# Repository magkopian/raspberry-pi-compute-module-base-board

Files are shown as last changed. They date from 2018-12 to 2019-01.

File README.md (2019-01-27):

Raspberry Pi Compute Module Base Board
================================

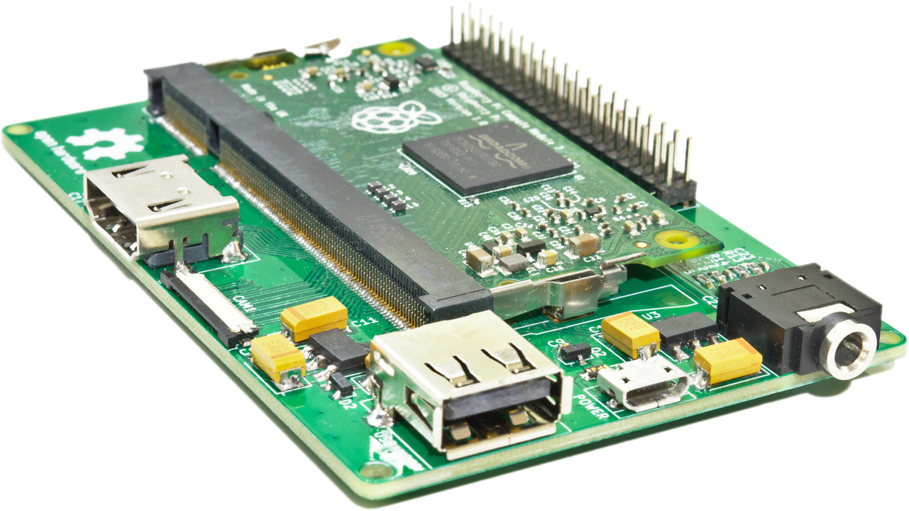
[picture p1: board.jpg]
Device


## Description:

These are the design files for a circuit board intended to be used as a base for other custom PCB designs that make use of the Raspberry Pi Compute Module.

If you want to design a custom PCB based on the Raspberry Pi Compute Module but you have never done it before, this project can serve as a starting point. The board is designed on KiCAD which is an open source and cross-platform EDA software, in order to allow as many people as possible to take advantage of it.

More information about the project can be found on [Instructables](https://www.instructables.com/id/Design-Your-Own-Raspberry-Pi-Compute-Module-PCB/).

## License:

Raspberry Pi Compute Module Base Board

Copyright (C) 2018  Manolis Agkopian

This program is free software: you can redistribute it and/or modify it under the terms of the GNU General Public License as published by the Free Software Foundation, either version 3 of the License, or (at your option) any later version.

This program is distributed in the hope that it will be useful, but WITHOUT ANY WARRANTY; without even the implied warranty of MERCHANTABILITY or FITNESS FOR A PARTICULAR PURPOSE. See the GNU General Public License for more details.

You should have received a copy of the GNU General Public License along with this program. If not, see https://www.gnu.org/licenses/.

### Third party schematic symbols and footprints:

This project makes use of the CM schematic symbols and DDR2 SODIMM fooprint designed by [Joan The Spark](https://github.com/JoanTheSpark/KiCAD) and distrubuted under the [GNU General Public License Version 3](https://www.gnu.org/licenses/gpl.html).

It also makes use of the HDMI connector schematic symbol from the [Digikey KiCAD Library](https://github.com/digikey/digikey-kicad-library) repository which is distrubuted under the [Creative Commons CC-BY-SA 4.0](https://creativecommons.org/licenses/by-sa/4.0).

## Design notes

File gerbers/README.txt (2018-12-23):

Filename                        Description
=============================================================

compute_module-B.Cu.gbl          Bottom Copper Layer

compute_module-In1.Cu.g2         Inner Copper Layer 1

compute_module-In2.Cu.g3		 Inner Copper Layer 2

compute_module-F.Cu.gtl          Front Copper Layer

compute_module-F.Mask.gts        Front Soldermask

compute_module-B.Mask.gbs        Bottom Soldermask

compute_module-F.SilkS.gto       Front Silkscreen

compute_module-B.SilkS.gbo       Bottom Silkscreen

compute_module-Edge.Cuts.gm1     Mechanical Layer (Board Outline)

compute_module.drl               Drill File

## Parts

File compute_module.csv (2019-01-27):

Title | Raspberry Pi Compute Module Base Board
Revision | A
Date
Generated | Sun 27 Jan 2019 08:12:45 AM EET
Company
Comment 1 | Copyright (C) 2018 Manolis Agkopian
Comment 2
Comment 3 | https://www.gnu.org/licenses/gpl.html
Comment 4 | License: GPLv3
Total Parts | 61
Total Unique Parts | 25
Ref | Qty | Value | Footprint | Datasheet
C1 C2 C3 C4 C5 C6 C7 C8 C9 C12 C13 C17 C18 C19 | 14 | 100nF | Capacitors_SMD:C_0402
C10 C11 C14 C15 C16 | 5 | 10uF | Capacitors_Tantalum_SMD:CP_Tantalum_Case-C_EIA-6032-28_Reflow
C20 C21 | 2 | 10uF | Capacitors_SMD:C_0805
C22 C23 | 2 | 33nF | Capacitors_SMD:C_0402
D1 | 1 | GREEN LED | LEDs:LED_0805
D2 D3 | 2 | BAT54 | TO_SOT_Packages_SMD:SOT-23 | https://gr.mouser.com/datasheet/2/427/bat54-58352.pdf
D4 D5 D6 D7 D9 D10 | 6 | BAV99 | TO_SOT_Packages_SMD:SOT-23 | https://gr.mouser.com/datasheet/2/427/bav99g-266615.pdf
D8 | 1 | RED LED | LEDs:LED_0805
F1 | 1 | 2A 6V | Polyfuse_Bourns_MF-PSML:Polyfuse_0805 | https://gr.mouser.com/datasheet/2/54/Bourns_MF-PSML-1159396.pdf
J1 | 1 | 2001-1-2-21-00-BK | HDMI_MOLEX:HDMI_MOLEX_471510001 | https://gr.mouser.com/datasheet/2/276/0471510001_IO_CONNECTORS-170105.pdf
J2 | 1 | JC-128 | jc-128:JC-128 | https://www.tme.eu/en/Document/b2d3db3ed78affad83450dce59a7cdd9/jc-128.pdf
MD1 | 1 | Board_RPi_CM3_200pConnector_multipart | Conn_TE-DDR2-SODIMM:Conn_TE-DDR2-SODIMM-0.6-200P-doublesided | https://www.tme.eu/en/Document/4b83792fd18cac93e642ba1f5319bf1c/1473005-4.pdf
P1 | 1 | POWER | Connectors:USB_Micro-B | https://www.tme.eu/en/Document/b7989e722b05f5084c507fb3ad8f02cb/MX-105017-0001.pdf
P2 | 1 | HOST | Connectors:USB_A | https://gr.mouser.com/datasheet/2/643/bel_SS-52100-001-1216592.pdf
P3 | 1 | CAM1 | ffc_conn:FPC_22 | https://gr.mouser.com/datasheet/2/445/687122183722-1114273.pdf
P4 | 1 | CONN_02X20 | Pin_Headers:Pin_Header_Straight_2x20
Q1 Q3 | 2 | 2N7002P.215 | TO_SOT_Packages_SMD:SOT-23 | https://www.tme.eu/en/Document/fda24b70d66290936384ff869f03745e/2N7002P.pdf
Q2 | 1 | DMP3056L-7 | TO_SOT_Packages_SMD:SOT-23 | https://www.tme.eu/en/Document/250d260377fe1e01ee709e3eafa0c268/DMP3056L.pdf
R1 R6 R7 R8 | 4 | 100K | Resistors_SMD:R_0603_HandSoldering
R2 R3 R11 | 3 | 1K | Resistors_SMD:R_0603_HandSoldering
R4 R5 R9 R10 | 4 | 1.8K | Resistors_SMD:R_0603_HandSoldering
R12 R13 | 2 | 150R | Resistors_SMD:R_0603_HandSoldering
R14 R15 | 2 | 270R | Resistors_SMD:R_0603_HandSoldering
U1 | 1 | REG1117-3.3 | TO_SOT_Packages_SMD:SOT-223-3_TabPin2 | http://www.ti.com/lit/ds/symlink/reg1117.pdf
U3 | 1 | REG1117A-1.8 | TO_SOT_Packages_SMD:SOT-223-3_TabPin2 | http://www.ti.com/lit/ds/symlink/reg1117a.pdf
BOM made with KICAD_BOM_WIZARD (https://github.com/HashDefineElectronics/KiCad_BOM_Wizard.git)
Generated Sun 27 Jan 2019 08:12:45 AM EET

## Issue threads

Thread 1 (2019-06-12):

Error opening schematic in latest Eagle 9.4.1

dattasaurabh82, 2019-06-12:
Hello I have trouble opening the .sch file in Latest Autodesk eagle.
Here's what it shows: [error window dialog](https://i.ibb.co/5B8Dkq0/Screen-Shot-2019-06-12-at-12-17-03-PM.png)
Any leads would help.

magkopian, 2019-06-12:
The board is designed on [KiCAD](http://kicad-pcb.org/) not Eagle, you need to use KiCAD to open the schematic and the rest of the design files.

Closed 2019-06-12.

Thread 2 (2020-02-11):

Board Design

mrsstaceyseigle, 2020-02-11:
Could you put together a board for me that only has 1 usb port, and power. Also could you help with integrating Ethernet port and wifi without using usb dongle

boulnat, 2020-02-12:
Hi, let me have a look at your request.
Do you need to be able to switch between Ethernet and WiFi or do you need both at the same time ?
I guess you will need hdmi to configure your board ?
What do you mean by USB port and power ?

magkopian, 2020-02-13:
@mrsstaceyseigle I'm not quite sure what you mean by "1 usb port, and power". The board already has one USB Type A connector for attaching USB devices and a micro USB used for power.

As for adding Ethernet and WiFi to the board that will depends on your requirements. For example, if you are fine with 10Mbit Ethernet probably the easiest way is to use an [ENC28J60](http://ww1.microchip.com/downloads/en/DeviceDoc/39662e.pdf) as it doesn't require a lot of external components and uses the SPI bus. You can have a look on page 7 of the datasheet for an application diagram.

I also designed a microcontroller board based on it in the past, that was though a long time ago and was done on Eagle but [here](https://www.instructables.com/id/PIC18-Development-Board-with-Ethernet-and-USB/) is the project if you want to have a look. The PCB design files are attached at the end of step 2. Regarding the Pi specifically I've never attempted to connect an ENC28J60 to it via SPI, but I do know a driver for this chip already exists in the Linux kernel for a while now and quite a few people where successful doing so.

As for WiFi, probably the easiest way is to use an ESP8266 module as it should require virtually no external components. That's not something I've done myself, but I'm aware of people using ESP8266 modules to [add WiFi](http://pwiatrowski.com/technology/raspberry-pi-zero-esp8266-internet/) to Raspberry Pi Zero based projects before the release of the W variant that features WiFi.

mrsstaceyseigle, 2020-02-13:
I was hoping to make a board like in the photo. Ethernet could be 10Mbit as all will be done is transfering text data very fast. Mainly looking at stable connection with Ethernet. Wifi could be 10Mbit too as long as there are not connection issues with newer routers.

My question also would be lets say that we went with a wifi module or Ethernet Module that required more components would they connect to the same points (bus) as the units your mention.

magkopian and boulnat could you put together a board layout like shown in this photo. A very narrow and small board that is a little bigger than the raspberry pi compute module on requested components
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

magkopian, 2020-02-13:
> Ethernet could be 10Mbit as all will be done is transfering text data very fast. Mainly looking at stable connection with Ethernet. Wifi could be 10Mbit too as long as there are not connection issues with newer routers.

If all you need to do is transfer text data then an ENC28J60 Ethernet controller as well as an ESP8266 WiFi module, should be both perfectly fine for your needs.

> My question also would be lets say that we went with a wifi module or Ethernet Module that required more components would they connect to the same points (bus) as the units your mention.

Depends on the chip, the ENC28J60 for example connects to the SPI bus but there are other ICs like for example the LAN9512 used by the original Raspberry Pi Model B that connect to the USB bus.

The LAN9512 also functions as a 2-port USB hub and with it you get 100Mbit Ethernet. But it's harder to use compared to the ENC28J60, as it requires more external components and is only available as a QFN package as far as I'm aware which makes it harder to solder. That is though the chip I'd personally use if I wanted to add Ethernet to a CM based project, unless I knew for a fact that I won't be needing 100Mbit Ethernet and wanted to drop the production cost as much as possible, as the cost of just the LAN9512 is more or less double that of an ENC28J60.

> could you put together a board layout like shown in this photo. A very narrow and small board that is a little bigger than the raspberry pi compute module on requested components

If your question is whether I can design a board like this, then the answer is certainly. However, that doesn't mean I also have the time to work on something like that at this point in time. I can provide you with advice for designing a board yourself (or by hiring someone else to do it for you), but can't really help much more than that.

Designing a version of my board that will feature at least Ethernet connectivity is something I myself wanted to do eventually anyway, but don't count on this happening any time soon.

mrsstaceyseigle, 2020-02-14:
Quick question. Is there a way we can change the size (width) of the current board design you have without causing issues to the traces or will the traces adjust as well. I needed to shrink the board size down 3 mm

magkopian, 2020-02-14:
@mrsstaceyseigle That depends, if after shrinking it you have traces outside the board outline there isn't much you can do about it, you need to move them. Instead of actually moving them though, it's probably easier to just delete the problematic traces and reroute them.

If you have no traces outside the board outline then just press `B` in order to redraw the ground planes, run a DRC check just to be sure and you should be good to go.

mrsstaceyseigle, 2020-02-20:
Could you provide me with the outer dimensions (size) of this board

magkopian, 2020-02-21:
@mrsstaceyseigle Sure, it's 93.25mm x 62.25mm.

mrsstaceyseigle, 2020-02-26:
Do you have any suggestion of board manufactures to use that are able to make this pcb board. Fast turn times

magkopian, 2020-02-27:
So, far I have experience with [ALLPCB](https://www.allpcb.com/), [JLCPCB](https://jlcpcb.com/) and [PCBWay](https://www.pcbway.com/). Don't have anything negative to say for any of them and generally they were all pretty fast each time I used them. For this board specifically I used ALLPCB and I was pretty happy with the result.

Only thing I'm not sure about is regarding the effect the recent outbreak had, as all these companies are based in China. It's been at least a couple of months since the last time I ordered PCBs from China so I can't tell you for certain that there won't be any delays.

Closed 2020-03-05.

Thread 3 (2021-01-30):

Base board evolution and secondary camera (CAM0)

blazczak, 2021-01-30:
Kudos @magkopian for creating this base board and for sharing it with us here.

The CM4 revision is now out (with the KiCad schematic entirely open sourced) but this is still of value to those tinkerers who have a few CM3/CM3+ boards laying around. Two questions for you:

In your real world experience using this base board, did you find it suitable for your needs or have you felt like you needed to make (or have you made since) any modifications to rev A.? If so, could you post your updates to this repo.

Secondly: the CM modules, contrasted with the mainstream A/B boards, offer hardware support for two cameras; I noticed you're only breaking out one of the cameras in Rev. A. I also see there's room on the board for the second connector, if one were inclined to reuse the same board dimensions. From your experience, any issues or considerations with adding another connector and traces for CAM0 to this base board design?

Thanks a bunch

magkopian, 2021-01-31:
> The CM4 revision is now out (with the KiCad schematic entirely open sourced) but this is still of value to those tinkerers who have a few CM3/CM3+ boards laying around.

Yes, when the CM4 was released and I read that the Raspberry Pi Foundation also released KiCAD design files for the IO board I was super happy. That was exactly what I was hopping to happen when I released my own project.

> In your real world experience using this base board, did you find it suitable for your needs or have you felt like you needed to make (or have you made since) any modifications to rev A.? If so, could you post your updates to this repo.

No, I haven’t made any modifications and if I had I've already posted a new revision. Also, now that the CM4 is also out a new revision of this board is unlikely.

> From your experience, any issues or considerations with adding another connector and traces for CAM0 to this base board design?

The only issue is that you will most likely have to drop the pin-to-pin compatibility of the 40-pin GPIO header with the regular Raspberry Pi boards. If this is not a feature that you need, which most likely isn’t unless you plan using HATs designed for the Regular raspberry Pi boards in your design, then there should be no problem.

To use the second camera you also need modify the pin definitions in the device tree, but I'm sure your already aware of that and also the official documentation is very comprehensive on the matter.

blazczak, 2021-02-08:
> No, I haven’t made any modifications and if I had I've already posted a new revision. Also, now that the CM4 is also out a new revision of this board is unlikely.

Understood. I was just making sure there weren't any in-flight changes before I fork this; thanks for your diligence.

> The only issue, is that you will most likely have to drop the pin-to-pin compatibility of the 40-pin GPIO header with the regular Raspberry Pi boards. If this is not a feature that you need, which most likely isn’t unless you plan using HATs designed for the regular Raspberry Pi boards with your design, then there should be no problem.

Good point. Indeed, I noticed that the 2nd I2C port is taken up by the 2nd camera if configured. I've made two GPIO pins from the original pool only available for CAM0 but will allow its SDA/SCL pins to accept other I2C devices on the 40-pin GPIO header, for the compatibility you've mentioned.

> To use the second camera you also need to modify the pin definitions in the device tree, but I'm sure you're already aware of that and also the official documentation is very comprehensive on the matter.

Thanks, yeah I was previously able to configure the blob using the original I/O board for both Raspberry Pi OS _and_ Ubuntu 20.

blazczak, 2021-02-08:
I've made changes to the forked schematic to bring in CAM0 and switch CAM1 and CAM0 pin assignments to match the Raspberry Pi [instructions on the foundation website](https://www.raspberrypi.org/documentation/hardware/computemodule/cmio-camera.md) (for the reason that it might be easier to follow and/or troubleshoot for folks who are just starting out with this board revision or simply desire compatibility between this board and the RPi I/O board).
The fork for the CAM0+CAM1 version is located at https://github.com/blazczak/raspberry-pi-compute-module-base-board/

Could you take a look @magkopian? The remaining step is putting down the actual tracks in the existing layout, but being an EE novice I'm a bit apprehensive with that step.

magkopian, 2021-02-12:
Unless I'm missing something I don't see any issues with the schematic. As for the PCB layout my advice is to try and keep all the traces as sort as possible and avoid using vias if you can help it. Also, make sure you have a solid ground plane going underneath the signals and use the built-in feature in KiCAD to route the differential signals as pairs. It's really not that hard as it sounds, as long as you stick to these rules you should be fine.

blazczak, 2021-03-22:
Thanks for the pointers. I have the first revision of the PCB layout for CAM0+CAM1.

I kept getting mapping errors when opening the project in KiCAD 5 and since I'm new at this I didn't want to risk propagating an incorrect auto remapping so I didn't proceed until I found a resolution - it took me a a few tries but I realized that I should just open this pre-existing project in KiCAD 4.x to force the use of old library definitions.

Keep in mind I'm a much better software engineer than electrical engineer. 😃 I tried to keep the majority of your original layout intact to keep "damage" at a minimum, so as a result some of the CAM0 traces are not not necessarily their shortest. I also didn't end up using the auto feature for differential signals, and I guess if they are of different lengths then I may have a problem? One remapping for the USB connector was force-rescued by KiCAD 4.0.7.

@magkopian could you take a look at the modified pcb in the above repo and let me know your comments?

blazczak, 2021-03-25:
KiCAD has some annoying UI bugs, at least on Mac: I had to redo large parts of track segments as it considered them connected for the purpose of ratsnest but the total length calculator was not "seeing" all segments in a particular track.

Added some finishing touches, including tuning the lengths of CAM0 differential pairs and revving the board code. I will create a PR to have this all reviewed and hopefully merged in.

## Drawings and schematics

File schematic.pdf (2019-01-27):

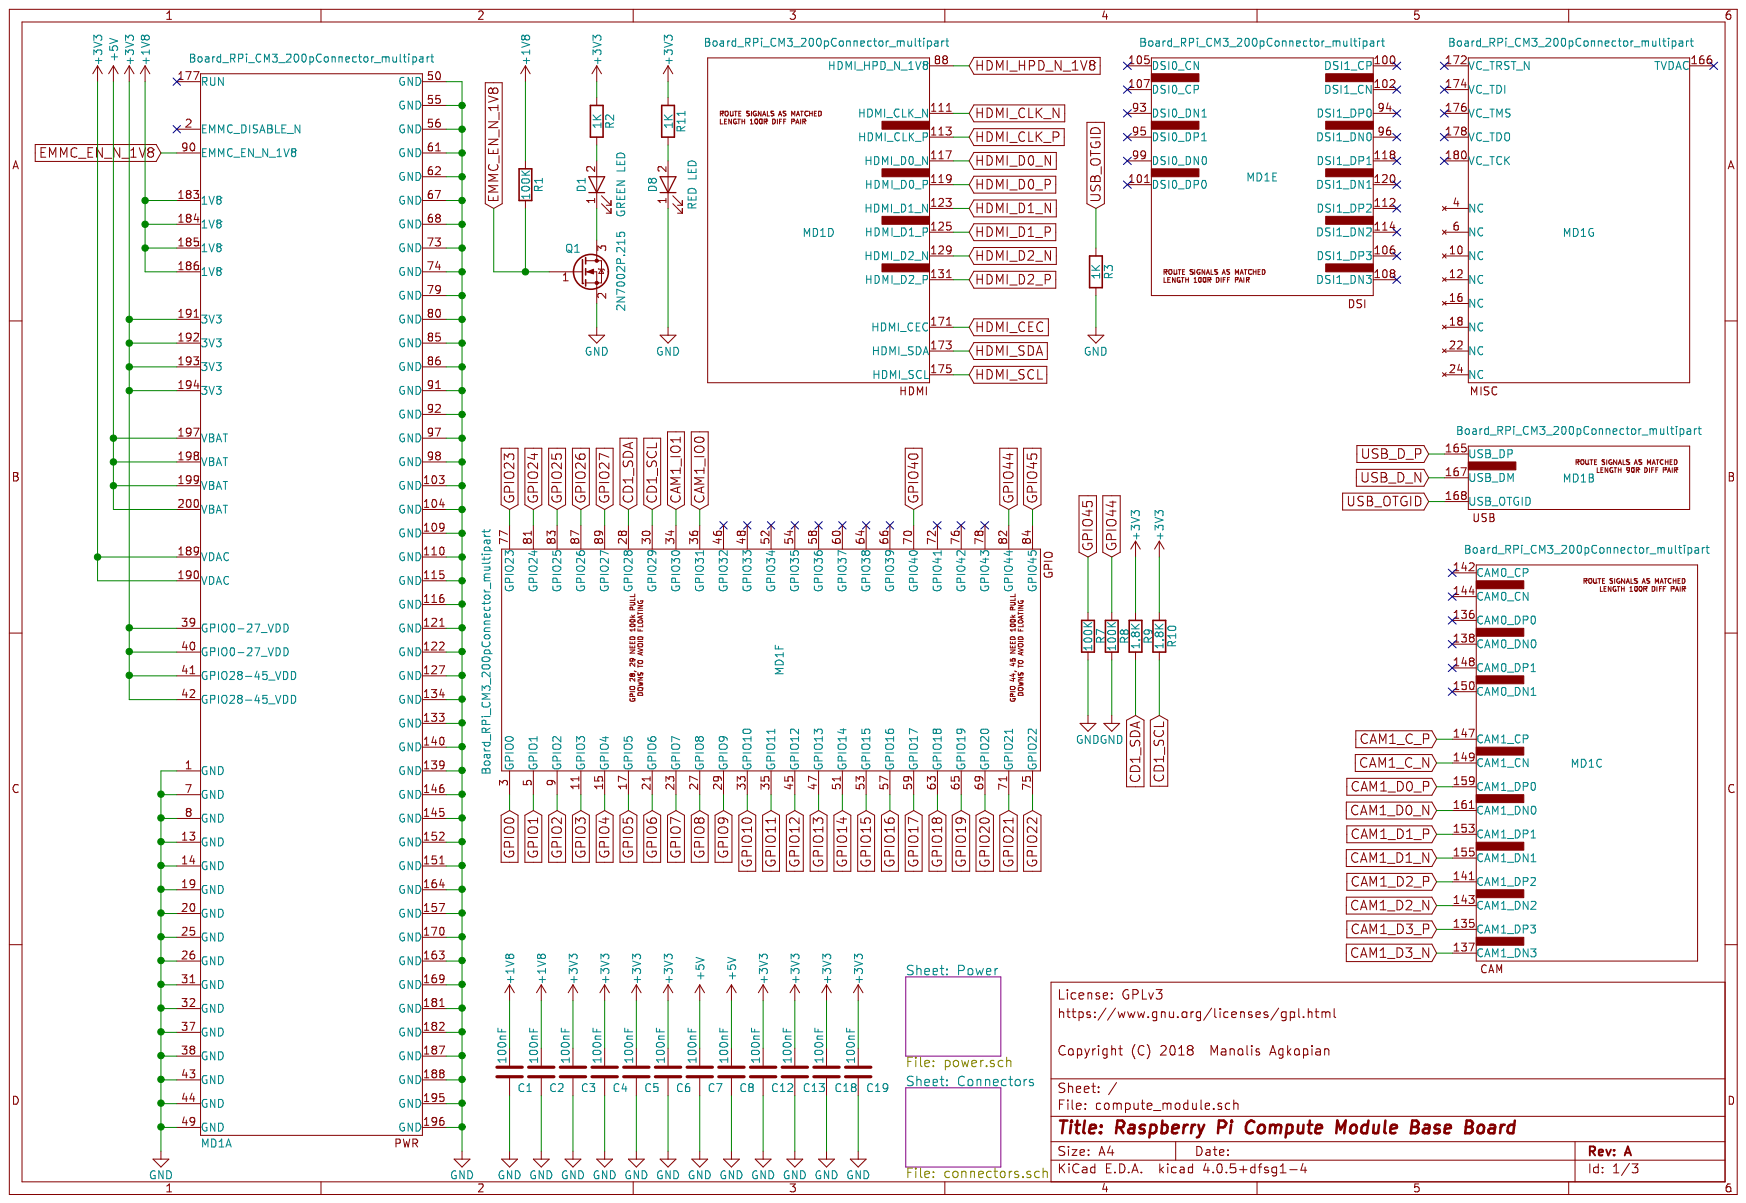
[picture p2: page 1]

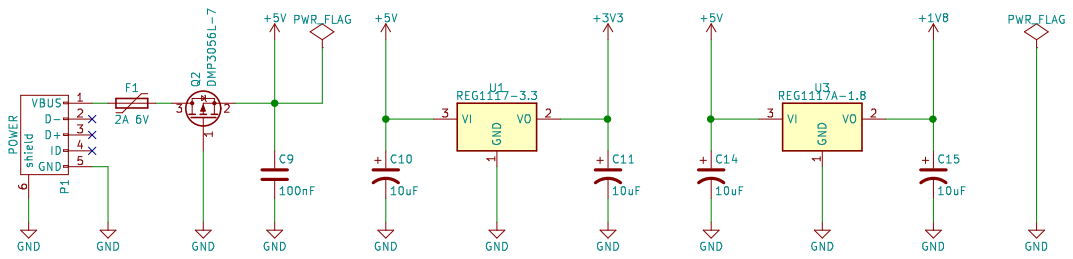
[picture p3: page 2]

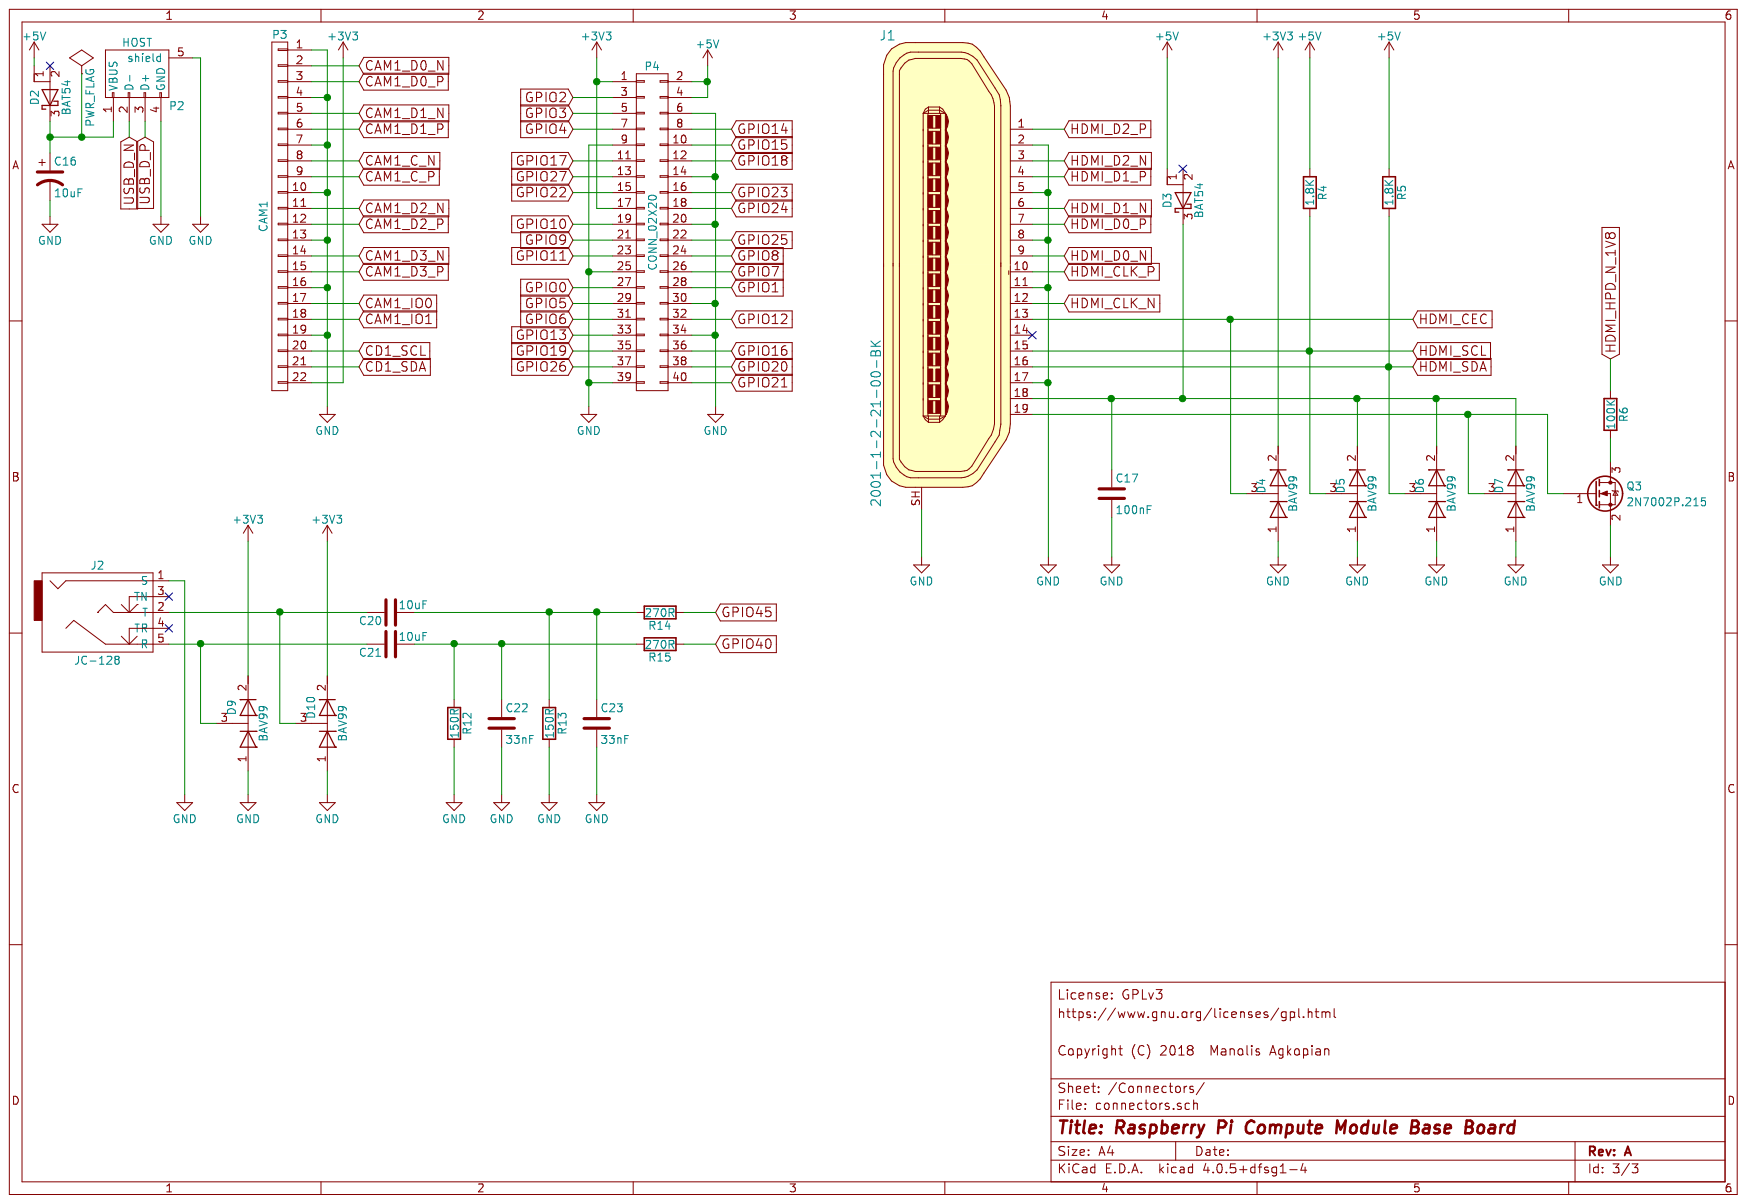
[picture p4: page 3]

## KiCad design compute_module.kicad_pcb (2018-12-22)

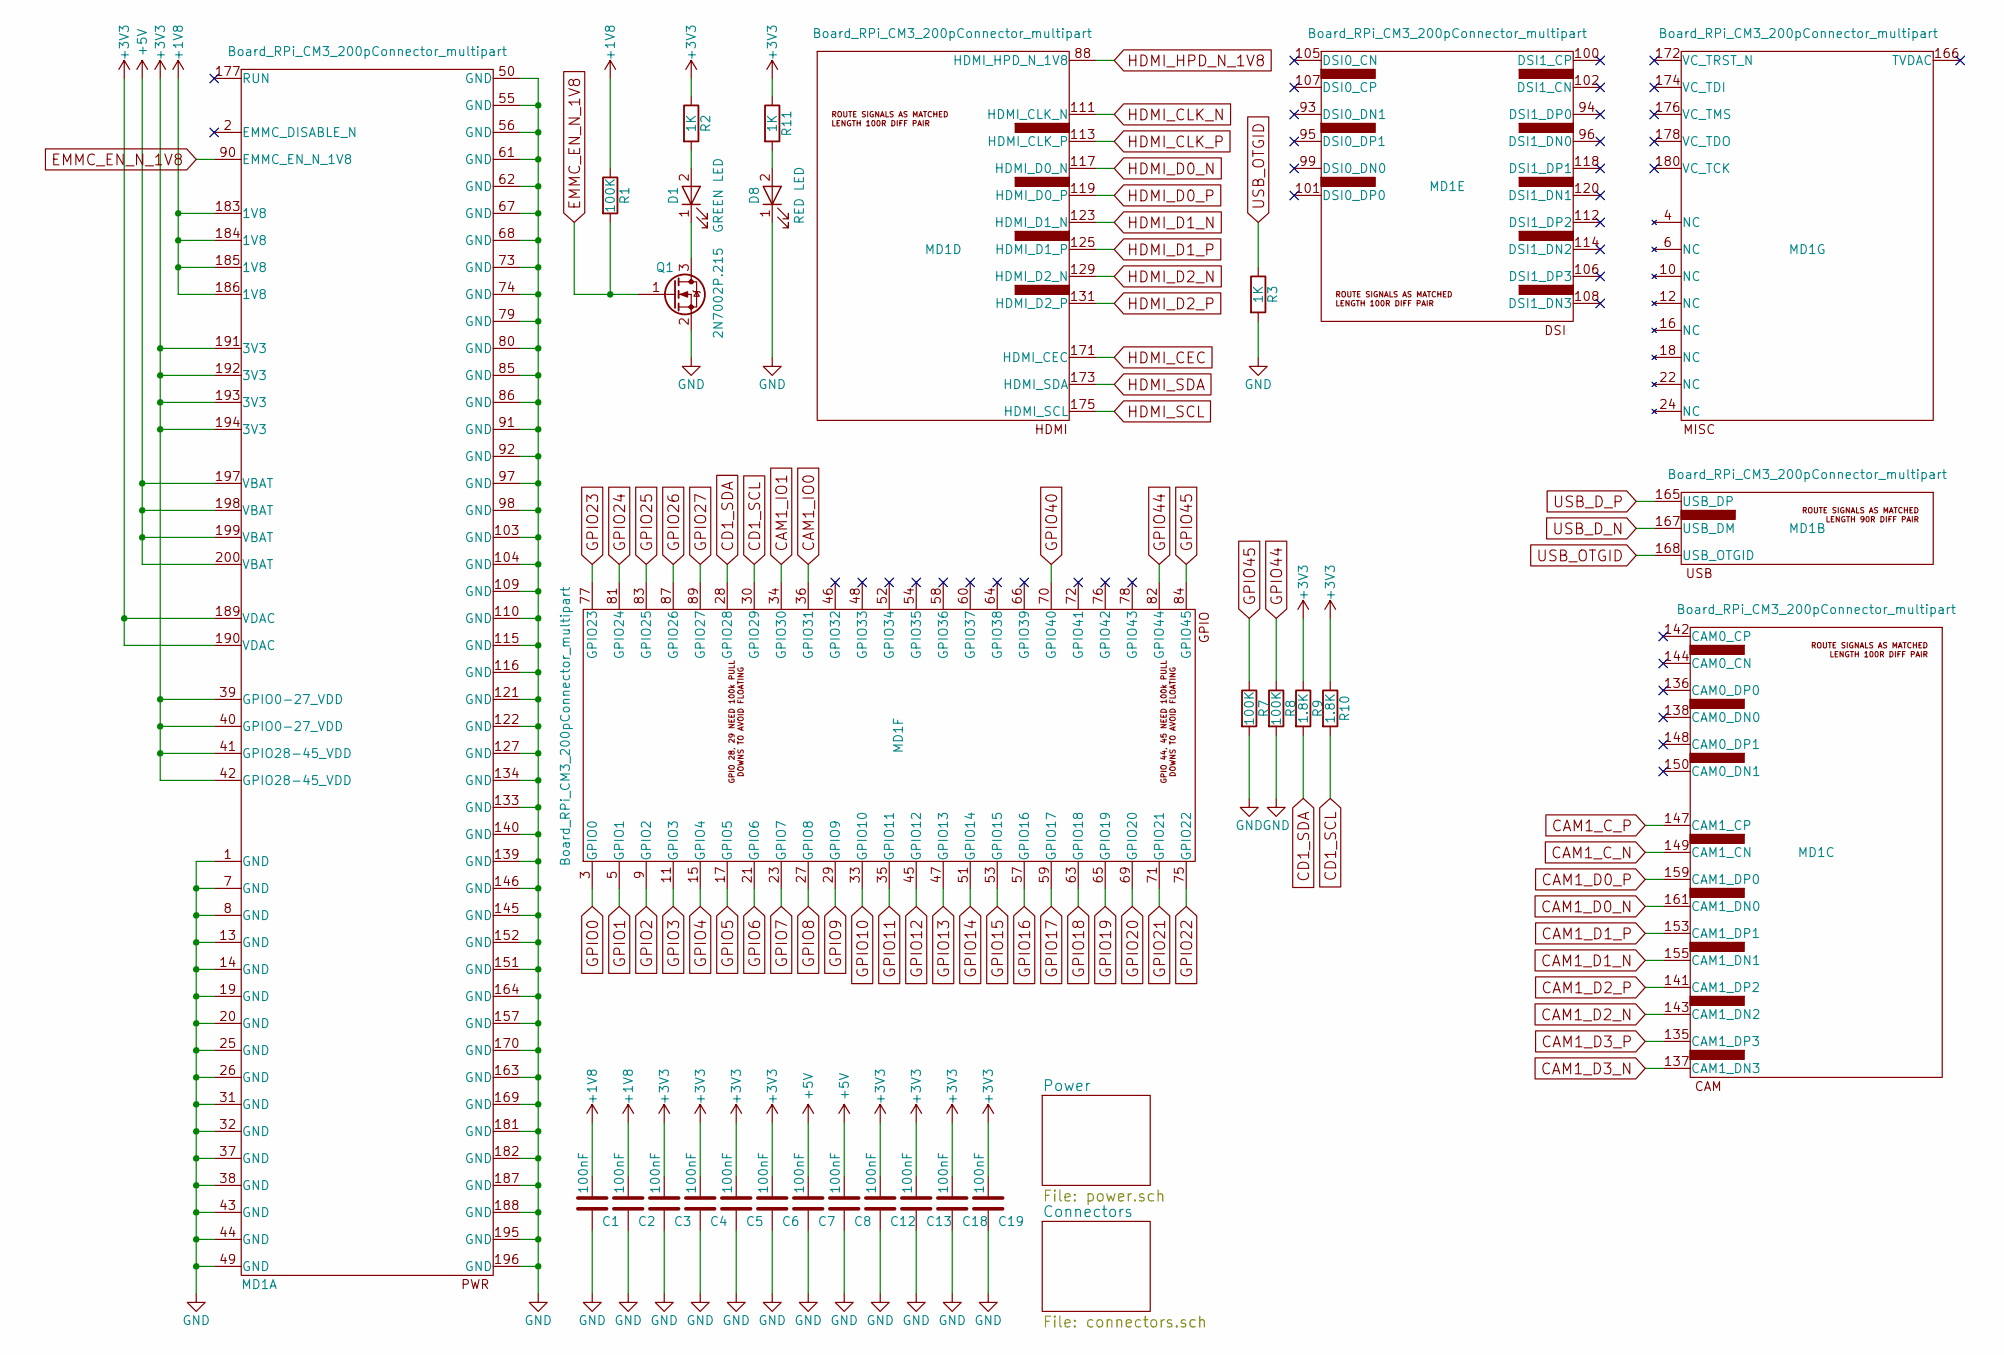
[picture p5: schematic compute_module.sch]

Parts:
C1, C2, C3, C4, C5, C6, C7, C8, C12, C13, C18, C19: 100nF; C_0402
D1: GREEN LED; LED_0805
D8: RED LED; LED_0805
MD1: Board_RPi_CM3_200pConnector_multipart; Conn_TE-DDR2-SODIMM-0.6-200P-doublesided
Q1: 2N7002P.215; SOT-23
R1, R7, R8: 100K; R_0603_HandSoldering
R2, R3, R11: 1K; R_0603_HandSoldering
R9, R10: 1.8K; R_0603_HandSoldering

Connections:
+1V8: C1.1, C2.1, MD1.183 (1V8), MD1.184 (1V8), MD1.185 (1V8), MD1.186 (1V8), R1.1; also elsewhere on the board
+3V3: C3.1, C4.1, C5.1, C6.1, C12.1, C13.1, C18.1, C19.1, MD1.39 (GPIO0-27_VDD), MD1.40 (GPIO0-27_VDD), MD1.41 (GPIO28-45_VDD), MD1.42 (GPIO28-45_VDD), MD1.189 (VDAC), MD1.190 (VDAC), MD1.191 (3V3), MD1.192 (3V3), MD1.193 (3V3), MD1.194 (3V3), R2.1, R9.1, R10.1, R11.1; also elsewhere on the board
+5V: C7.1, C8.1, MD1.197 (VBAT), MD1.198 (VBAT), MD1.199 (VBAT), MD1.200 (VBAT); also elsewhere on the board
CAM1_C_N: MD1.149 (CAM1_CN); also elsewhere on the board
CAM1_C_P: MD1.147 (CAM1_CP); also elsewhere on the board
CAM1_D0_N: MD1.161 (CAM1_DN0); also elsewhere on the board
CAM1_D0_P: MD1.159 (CAM1_DP0); also elsewhere on the board
CAM1_D1_N: MD1.155 (CAM1_DN1); also elsewhere on the board
CAM1_D1_P: MD1.153 (CAM1_DP1); also elsewhere on the board
CAM1_D2_N: MD1.143 (CAM1_DN2); also elsewhere on the board
CAM1_D2_P: MD1.141 (CAM1_DP2); also elsewhere on the board
CAM1_D3_N: MD1.137 (CAM1_DN3); also elsewhere on the board
CAM1_D3_P: MD1.135 (CAM1_DP3); also elsewhere on the board
CAM1_IO0: MD1.36 (GPIO31); also elsewhere on the board
CAM1_IO1: MD1.34 (GPIO30); also elsewhere on the board
CD1_SCL: MD1.30 (GPIO29), R10.2; also elsewhere on the board
CD1_SDA: MD1.28 (GPIO28), R9.2; also elsewhere on the board
EMMC_EN_N_1V8: MD1.90 (EMMC_EN_N_1V8), Q1.1 (G), R1.2
GND: C1.2, C2.2, C3.2, C4.2, C5.2, C6.2, C7.2, C8.2, C12.2, C13.2, C18.2, C19.2, D8.1 (K), MD1.1 (GND), MD1.7 (GND), MD1.8 (GND), MD1.13 (GND), MD1.14 (GND), MD1.19 (GND), MD1.20 (GND), MD1.25 (GND), MD1.26 (GND), MD1.31 (GND), MD1.32 (GND), MD1.37 (GND), MD1.38 (GND), MD1.43 (GND), MD1.44 (GND), MD1.49 (GND), MD1.50 (GND), MD1.55 (GND), MD1.56 (GND), MD1.61 (GND), MD1.62 (GND), MD1.67 (GND), MD1.68 (GND), MD1.73 (GND), MD1.74 (GND), MD1.79 (GND), MD1.80 (GND), MD1.85 (GND), MD1.86 (GND), MD1.91 (GND), MD1.92 (GND), MD1.97 (GND), MD1.98 (GND), MD1.103 (GND), MD1.104 (GND), MD1.109 (GND), MD1.110 (GND), MD1.115 (GND), MD1.116 (GND), MD1.121 (GND), MD1.122 (GND), MD1.127 (GND), MD1.133 (GND), MD1.134 (GND), MD1.139 (GND), MD1.140 (GND), MD1.145 (GND), MD1.146 (GND), MD1.151 (GND), MD1.152 (GND), MD1.157 (GND), MD1.163 (GND), MD1.164 (GND), MD1.169 (GND), MD1.170 (GND), MD1.181 (GND), MD1.182 (GND), MD1.187 (GND), MD1.188 (GND), MD1.195 (GND), MD1.196 (GND), Q1.2 (S), R3.2, R7.2, R8.2; also elsewhere on the board
GPIO0: MD1.3 (GPIO0); also elsewhere on the board
GPIO1: MD1.5 (GPIO1); also elsewhere on the board
GPIO2: MD1.9 (GPIO2); also elsewhere on the board
GPIO3: MD1.11 (GPIO3); also elsewhere on the board
GPIO4: MD1.15 (GPIO4); also elsewhere on the board
GPIO5: MD1.17 (GPIO5); also elsewhere on the board
GPIO6: MD1.21 (GPIO6); also elsewhere on the board
GPIO7: MD1.23 (GPIO7); also elsewhere on the board
GPIO8: MD1.27 (GPIO8); also elsewhere on the board
GPIO9: MD1.29 (GPIO9); also elsewhere on the board
GPIO10: MD1.33 (GPIO10); also elsewhere on the board
GPIO11: MD1.35 (GPIO11); also elsewhere on the board
GPIO12: MD1.45 (GPIO12); also elsewhere on the board
GPIO13: MD1.47 (GPIO13); also elsewhere on the board
GPIO14: MD1.51 (GPIO14); also elsewhere on the board
GPIO15: MD1.53 (GPIO15); also elsewhere on the board
GPIO16: MD1.57 (GPIO16); also elsewhere on the board
GPIO17: MD1.59 (GPIO17); also elsewhere on the board
GPIO18: MD1.63 (GPIO18); also elsewhere on the board
GPIO19: MD1.65 (GPIO19); also elsewhere on the board
GPIO20: MD1.69 (GPIO20); also elsewhere on the board
GPIO21: MD1.71 (GPIO21); also elsewhere on the board
GPIO22: MD1.75 (GPIO22); also elsewhere on the board
GPIO23: MD1.77 (GPIO23); also elsewhere on the board
GPIO24: MD1.81 (GPIO24); also elsewhere on the board
GPIO25: MD1.83 (GPIO25); also elsewhere on the board
GPIO26: MD1.87 (GPIO26); also elsewhere on the board
GPIO27: MD1.89 (GPIO27); also elsewhere on the board
GPIO40: MD1.70 (GPIO40); also elsewhere on the board
GPIO44: MD1.82 (GPIO44), R8.1
GPIO45: MD1.84 (GPIO45), R7.1; also elsewhere on the board
HDMI_CEC: MD1.171 (HDMI_CEC); also elsewhere on the board
HDMI_CLK_N: MD1.111 (HDMI_CLK_N); also elsewhere on the board
HDMI_CLK_P: MD1.113 (HDMI_CLK_P); also elsewhere on the board
HDMI_D0_N: MD1.117 (HDMI_D0_N); also elsewhere on the board
HDMI_D0_P: MD1.119 (HDMI_D0_P); also elsewhere on the board
HDMI_D1_N: MD1.123 (HDMI_D1_N); also elsewhere on the board
HDMI_D1_P: MD1.125 (HDMI_D1_P); also elsewhere on the board
HDMI_D2_N: MD1.129 (HDMI_D2_N); also elsewhere on the board
HDMI_D2_P: MD1.131 (HDMI_D2_P); also elsewhere on the board
HDMI_HPD_N_1V8: MD1.88 (HDMI_HPD_N_1V8); also elsewhere on the board
HDMI_SCL: MD1.175 (HDMI_SCL); also elsewhere on the board
HDMI_SDA: MD1.173 (HDMI_SDA); also elsewhere on the board
unnamed: D1.1 (K), Q1.3 (D)
unnamed: D1.2 (A), R2.2
unnamed: D8.2 (A), R11.2
USB_D_N: MD1.167 (USB_DM); also elsewhere on the board
USB_D_P: MD1.165 (USB_DP); also elsewhere on the board
USB_OTGID: MD1.168 (USB_OTGID), R3.1

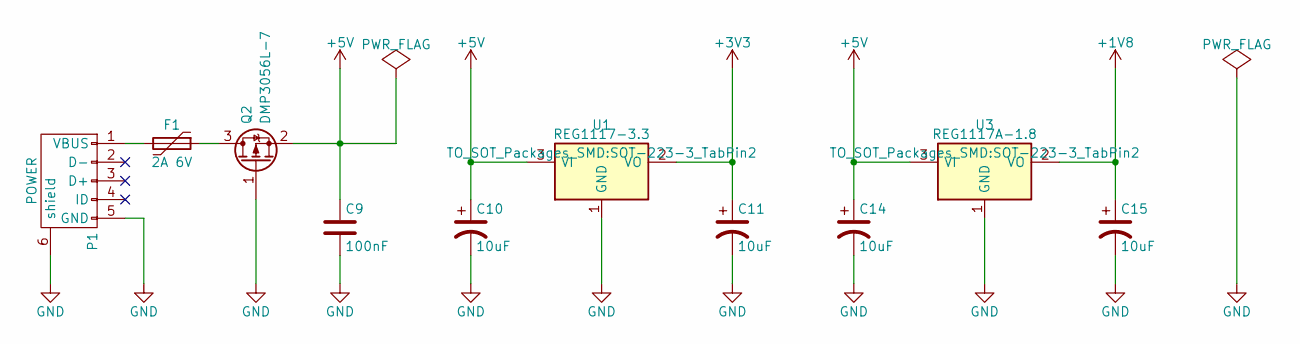
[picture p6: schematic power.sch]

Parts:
C9: 100nF; C_0402
C10, C11, C14, C15: 10uF; CP_Tantalum_Case-C_EIA-6032-28_Reflow
F1: 2A 6V; Polyfuse_0805
P1: POWER; USB_Micro-B
Q2: DMP3056L-7; SOT-23
U1: REG1117-3.3; SOT-223-3_TabPin2
U3: REG1117A-1.8; SOT-223-3_TabPin2

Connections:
+1V8: C15.1, U3.2 (VO); also elsewhere on the board
+3V3: C11.1, U1.2 (VO); also elsewhere on the board
+5V: C9.1, C10.1, C14.1, Q2.2 (S), U1.3 (VI), U3.3 (VI); also elsewhere on the board
GND: C9.2, C10.2, C11.2, C14.2, C15.2, P1.5 (GND), P1.6 (shield), Q2.1 (G), U1.1 (GND), U3.1 (GND); also elsewhere on the board
unnamed: F1.1, Q2.3 (D)
unnamed: F1.2, P1.1 (VBUS)

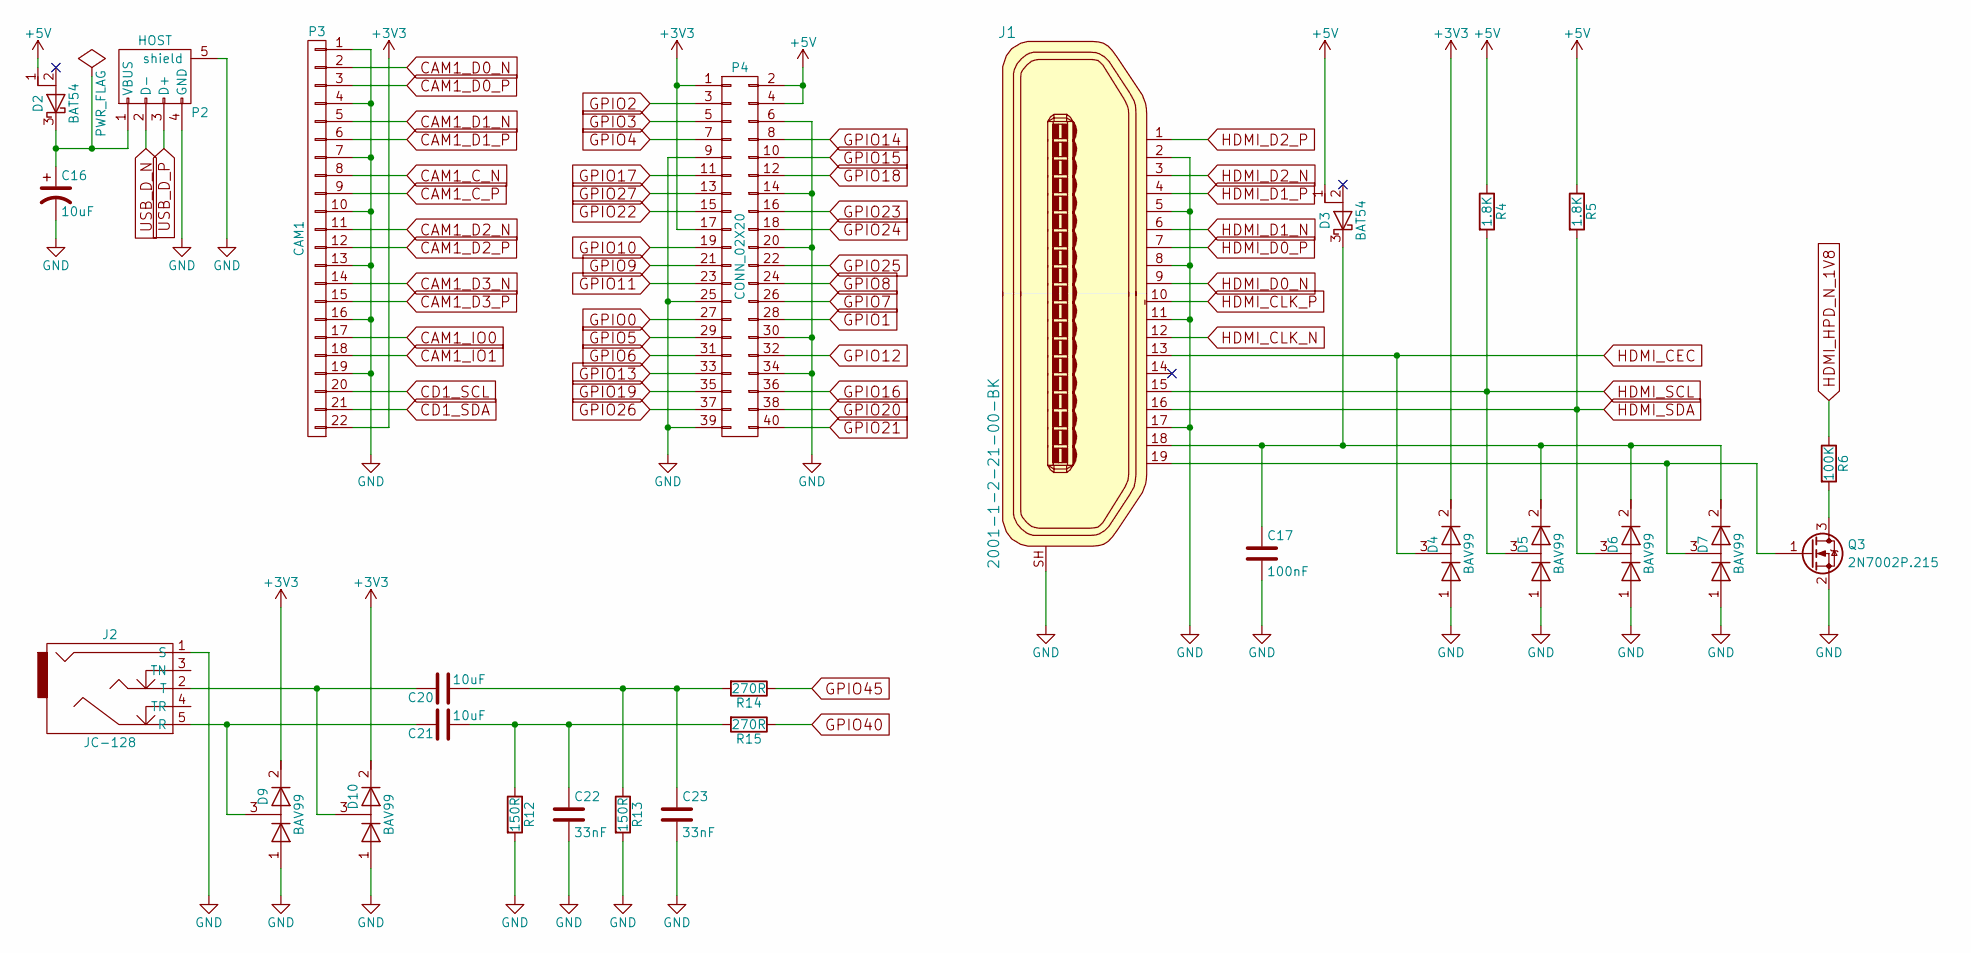
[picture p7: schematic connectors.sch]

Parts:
C16: 10uF; CP_Tantalum_Case-C_EIA-6032-28_Reflow
C17: 100nF; C_0402
C20, C21: 10uF; C_0805
C22, C23: 33nF; C_0402
D2, D3: BAT54; SOT-23
D4, D5, D6, D7, D9, D10: BAV99; SOT-23
J1: 2001-1-2-21-00-BK; HDMI_MOLEX_471510001; MPN 2001-1-2-21-00-BK; Digi-Key_PN 1175-1704-1-ND
J2: JC-128
P2: HOST; USB_A
P3: CAM1; FPC_22
P4: CONN_02X20; Pin_Header_Straight_2x20
Q3: 2N7002P.215; SOT-23
R4, R5: 1.8K; R_0603_HandSoldering
R6: 100K; R_0603_HandSoldering
R12, R13: 150R; R_0603_HandSoldering
R14, R15: 270R; R_0603_HandSoldering

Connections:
+3V3: D4.2 (K), D9.2 (K), D10.2 (K), P3.22, P4.1, P4.17; also elsewhere on the board
+5V: D2.1 (A), D3.1 (A), P4.2, P4.4, R4.1, R5.1; also elsewhere on the board
CAM1_C_N: P3.8; also elsewhere on the board
CAM1_C_P: P3.9; also elsewhere on the board
CAM1_D0_N: P3.2; also elsewhere on the board
CAM1_D0_P: P3.3; also elsewhere on the board
CAM1_D1_N: P3.5; also elsewhere on the board
CAM1_D1_P: P3.6; also elsewhere on the board
CAM1_D2_N: P3.11; also elsewhere on the board
CAM1_D2_P: P3.12; also elsewhere on the board
CAM1_D3_N: P3.14; also elsewhere on the board
CAM1_D3_P: P3.15; also elsewhere on the board
CAM1_IO0: P3.17; also elsewhere on the board
CAM1_IO1: P3.18; also elsewhere on the board
CD1_SCL: P3.20; also elsewhere on the board
CD1_SDA: P3.21; also elsewhere on the board
GND: C16.2, C17.2, C22.2, C23.2, D4.1 (A), D5.1 (A), D6.1 (A), D7.1 (A), D9.1 (A), D10.1 (A), J1.2, J1.5, J1.8, J1.11, J1.17, J1.SH, J2.1 (S), P2.4 (GND), P2.5 (shield), P3.1, P3.4, P3.7, P3.10, P3.13, P3.16, P3.19, P4.6, P4.9, P4.14, P4.20, P4.25, P4.30, P4.34, P4.39, Q3.2 (S), R12.2, R13.2; also elsewhere on the board
GPIO0: P4.27; also elsewhere on the board
GPIO1: P4.28; also elsewhere on the board
GPIO2: P4.3; also elsewhere on the board
GPIO3: P4.5; also elsewhere on the board
GPIO4: P4.7; also elsewhere on the board
GPIO5: P4.29; also elsewhere on the board
GPIO6: P4.31; also elsewhere on the board
GPIO7: P4.26; also elsewhere on the board
GPIO8: P4.24; also elsewhere on the board
GPIO9: P4.21; also elsewhere on the board
GPIO10: P4.19; also elsewhere on the board
GPIO11: P4.23; also elsewhere on the board
GPIO12: P4.32; also elsewhere on the board
GPIO13: P4.33; also elsewhere on the board
GPIO14: P4.8; also elsewhere on the board
GPIO15: P4.10; also elsewhere on the board
GPIO16: P4.36; also elsewhere on the board
GPIO17: P4.11; also elsewhere on the board
GPIO18: P4.12; also elsewhere on the board
GPIO19: P4.35; also elsewhere on the board
GPIO20: P4.38; also elsewhere on the board
GPIO21: P4.40; also elsewhere on the board
GPIO22: P4.15; also elsewhere on the board
GPIO23: P4.16; also elsewhere on the board
GPIO24: P4.18; also elsewhere on the board
GPIO25: P4.22; also elsewhere on the board
GPIO26: P4.37; also elsewhere on the board
GPIO27: P4.13; also elsewhere on the board
GPIO40: R15.1; also elsewhere on the board
GPIO45: R14.1; also elsewhere on the board
HDMI_CEC: D4.3 (common), J1.13; also elsewhere on the board
HDMI_CLK_N: J1.12; also elsewhere on the board
HDMI_CLK_P: J1.10; also elsewhere on the board
HDMI_D0_N: J1.9; also elsewhere on the board
HDMI_D0_P: J1.7; also elsewhere on the board
HDMI_D1_N: J1.6; also elsewhere on the board
HDMI_D1_P: J1.4; also elsewhere on the board
HDMI_D2_N: J1.3; also elsewhere on the board
HDMI_D2_P: J1.1; also elsewhere on the board
HDMI_HPD_N_1V8: R6.1; also elsewhere on the board
HDMI_SCL: D5.3 (common), J1.15, R4.2; also elsewhere on the board
HDMI_SDA: D6.3 (common), J1.16, R5.2; also elsewhere on the board
unnamed: C16.1, D2.3 (K), P2.1 (VBUS)
unnamed: C17.1, D3.3 (K), D5.2 (K), D6.2 (K), D7.2 (K), J1.18
unnamed: C20.1, C23.1, R13.1, R14.2
unnamed: C20.2, D10.3 (common), J2.2 (T)
unnamed: C21.1, C22.1, R12.1, R15.2
unnamed: C21.2, D9.3 (common), J2.5 (R)
unnamed: D7.3 (common), J1.19, Q3.1 (G)
unnamed: Q3.3 (D), R6.2
USB_D_N: P2.2 (D-); also elsewhere on the board
USB_D_P: P2.3 (D+); also elsewhere on the board

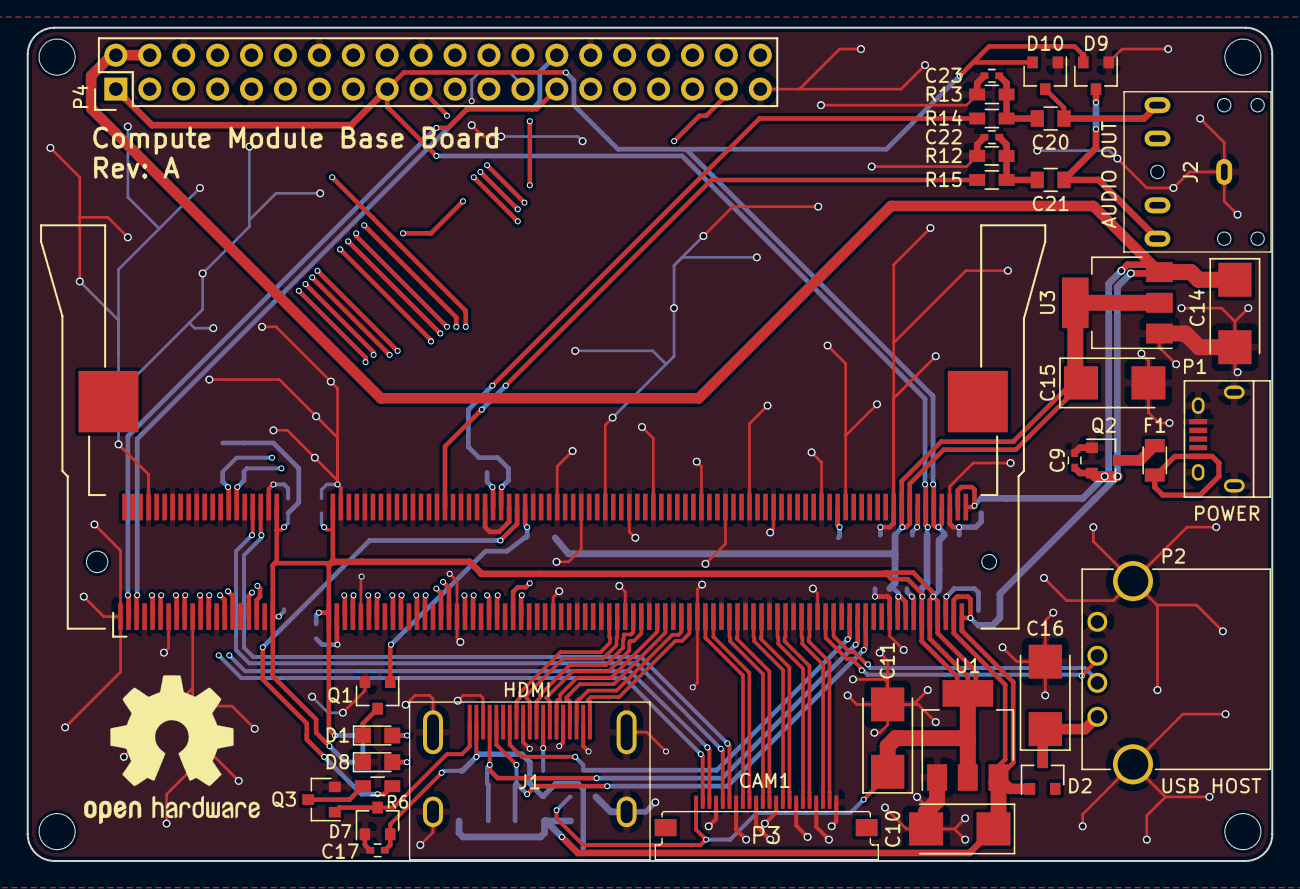
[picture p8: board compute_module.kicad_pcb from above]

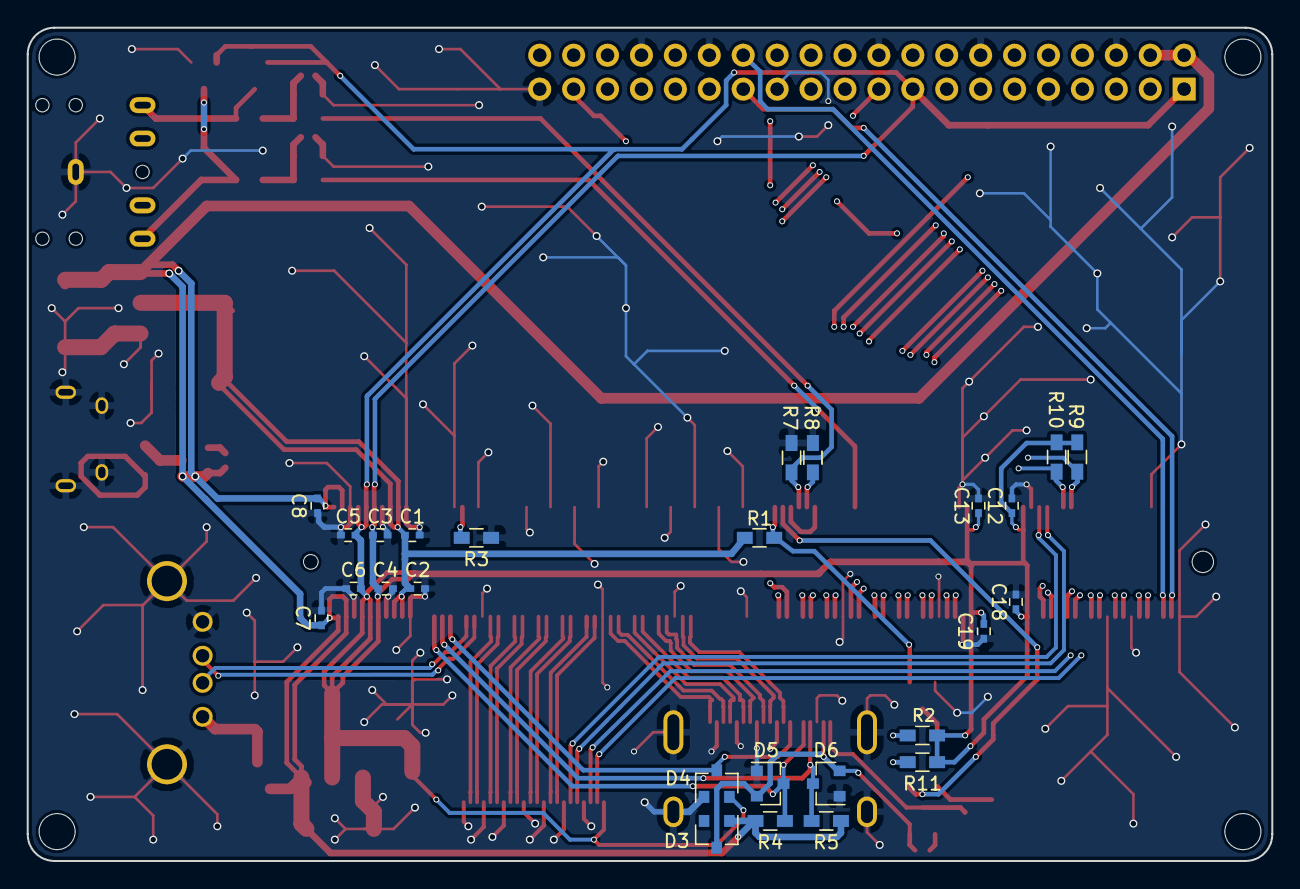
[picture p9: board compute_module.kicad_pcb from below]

Board: 4 copper layers, 93.2 x 62.4 mm, 61 parts (26 on the bottom side), 78 nets.

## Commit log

2018-12-13 Assigned footprints to most components
    [compute_module.sch, connectors.sch, power.sch]
2018-12-13 Added HDMI footprints
2018-12-14 Added camera connector footprint
    [connectors.sch]
2018-12-16 Laid down components
    [compute_module.sch]
2018-12-16 Replaced HDMI connector
    [compute_module.kicad_pcb, connectors.sch]
2018-12-16 Moved more components to the top
    [compute_module.kicad_pcb]
2018-12-17 Fixed fused
    [compute_module.csv, compute_module.kicad_pcb, connectors.sch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]
2018-12-17 Routed differential pairs for camera and HDMI
    [compute_module.kicad_pcb, compute_module.sch, connectors.sch]
2018-12-17 Routed the rest of the board
    [compute_module.kicad_pcb]
2018-12-17 Stitched ground planes with vias
    [compute_module.kicad_pcb]
2018-12-17 More via stitching
    [compute_module.kicad_pcb]
2018-12-18 Regenerated BOM
    [compute_module.csv]
2018-12-18 Removed 2.5V regulator and changed bottom ground plane clearence
    [compute_module.kicad_pcb, compute_module.sch, connectors.sch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]
2018-12-18 Added decoupling caps for gpio power pins
    [compute_module.kicad_pcb, compute_module.sch, connectors.sch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]
2018-12-18 Added pull-ups for gpio28, 29, 44 and 45
    [compute_module.kicad_pcb, compute_module.sch, connectors.sch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]
2018-12-18 Moved CAM1_IO0 and CAM1_IO1 to gpio 31 and 30
    [compute_module.kicad_pcb, compute_module.sch]
2018-12-18 Partially routed gpio header
    [compute_module.kicad_pcb, compute_module.sch, connectors.sch]
2018-12-19 Routed gpio header
    [compute_module.kicad_pcb]
2018-12-20 Changed ground via size
    [compute_module.kicad_pcb]
2018-12-20 Added labels on silkscreen
    [compute_module.kicad_pcb]
2018-12-21 Minor fixes and rounded board edges
    [compute_module.kicad_pcb]
2018-12-21 Moved camera sda and scl to gpio 28 and 29
    [compute_module.kicad_pcb, compute_module.sch, connectors.sch]
2018-12-21 Added power LED
    [compute_module.kicad_pcb, compute_module.sch, connectors.sch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]
2018-12-22 Minor fixes
    [compute_module.kicad_pcb, compute_module.sch]
2018-12-22 Added audio jack
    [compute_module.kicad_pcb, compute_module.sch, connectors.sch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]
2018-12-22 Cleaned up libs
    [compute_module.kicad_pcb, compute_module.sch]
2018-12-22 Replaced 1uF input cap with 100nF
    [compute_module.csv, compute_module.kicad_pcb, compute_module.sch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]
2018-12-23 Added license
    [compute_module.sch, connectors.sch, power.sch]
2018-12-23 Added license info for sodimm connector
2018-12-23 Added license info for hdmi schematic symbol
2018-12-23 Generated gerber files
    [compute_module-B.Cu.gbl, compute_module-B.Mask.gbs, compute_module-B.SilkS.gbo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]
2018-12-23 Added nc to unused audio jack pins
    [connectors.sch]
2019-01-27 Added datasheet links to BOM
    [compute_module.csv, compute_module.sch, connectors.sch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]
2019-01-27 Added board photo
2019-01-27 Added schematic PDF
2019-01-27 Added device tree file
